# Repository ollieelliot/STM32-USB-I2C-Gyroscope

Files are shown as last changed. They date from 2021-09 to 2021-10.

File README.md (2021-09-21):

# STM32-USB-I2C-Gyroscope
Connecting an STM32F405RG microcontroller with a gyroscope through I2C as well as connecting USB B Micro, SWD and USART in order to learn more about circuit and PCB design.
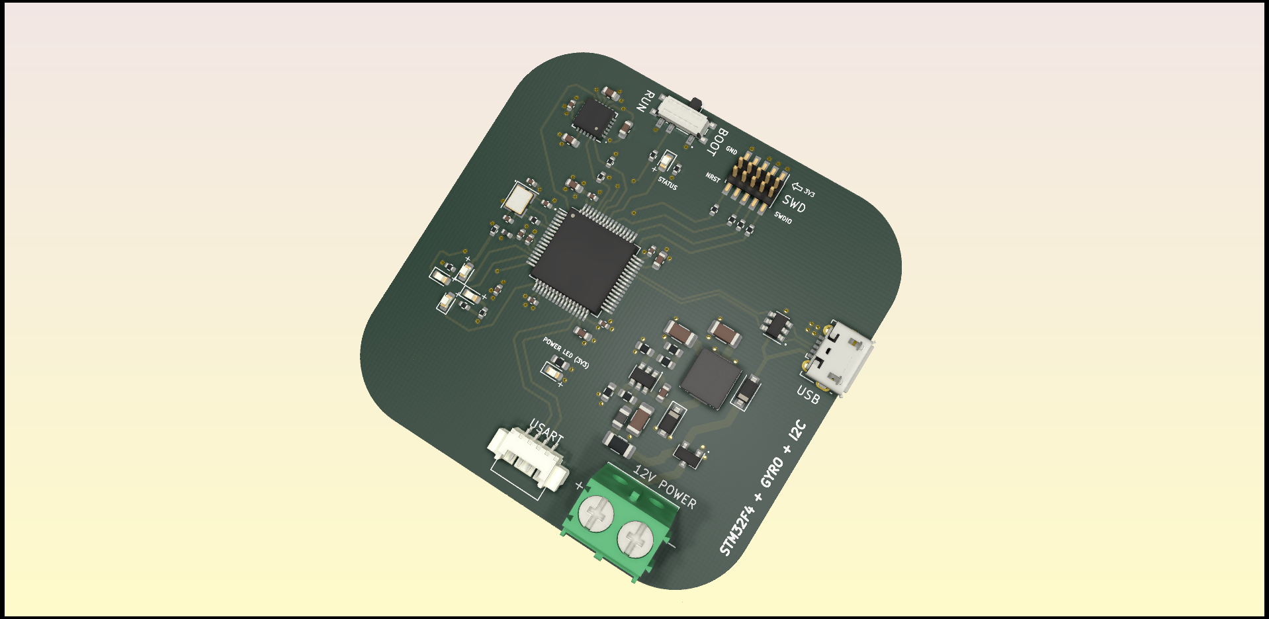
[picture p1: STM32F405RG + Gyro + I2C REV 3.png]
3D View


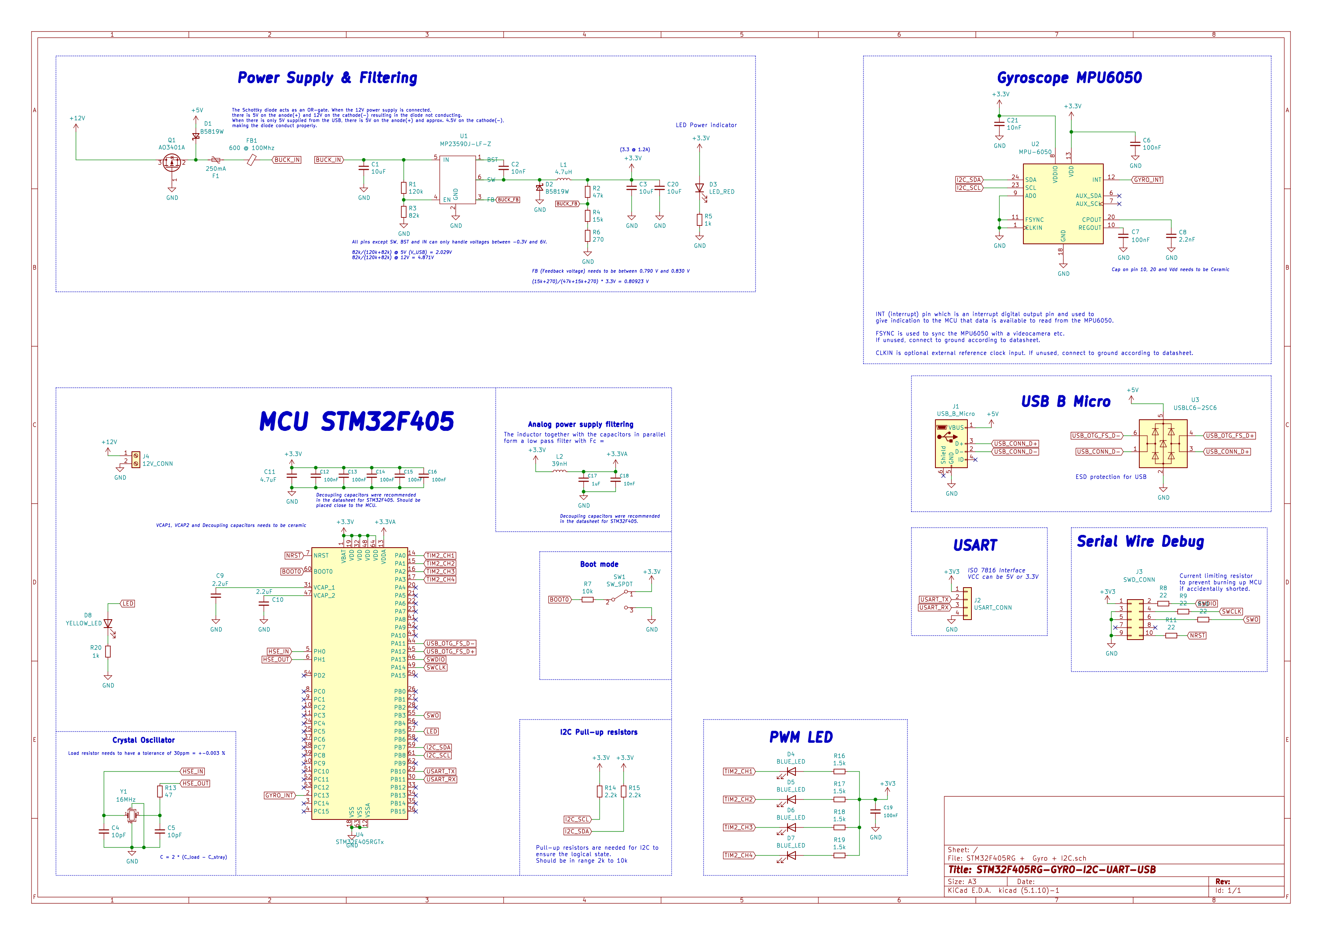
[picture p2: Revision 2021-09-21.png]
KiCad Schematic


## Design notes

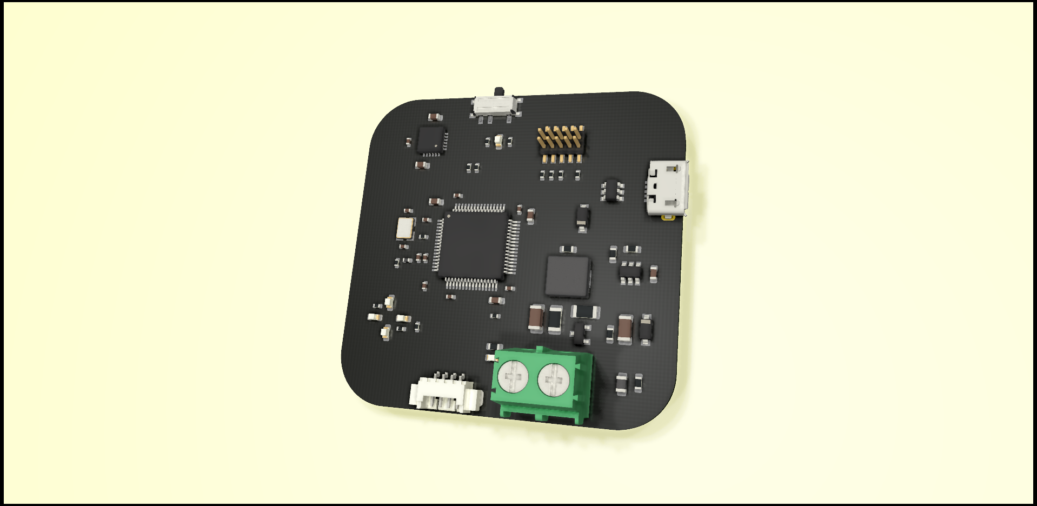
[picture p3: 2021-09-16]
STM32F405RG + Gyro + I2C.png

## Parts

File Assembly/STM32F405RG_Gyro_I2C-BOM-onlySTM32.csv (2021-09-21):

Comment | Designator | Footprint | LCSC
10uF | C1,C3,C20 | Capacitor_SMD:C_1206_3216Metric
4.7uF | C11 | Capacitor_SMD:C_0603_1608Metric
100nF | C6,C12,C13,C14,C15,C16,C19 | Capacitor_SMD:C_0402_1005Metric
1uF | C17 | Capacitor_SMD:C_0402_1005Metric
10nF | C18 | Capacitor_SMD:C_0402_1005Metric
10nF | C2,C21 | Capacitor_SMD:C_0603_1608Metric
10pF | C4,C5 | Capacitor_SMD:C_0402_1005Metric
100nF | C7 | Capacitor_SMD:C_0603_1608Metric
2.2nF | C8 | Capacitor_SMD:C_0603_1608Metric
2.2uF | C9,C10 | Capacitor_SMD:C_0603_1608Metric
B5819W | D1,D2 | Diode_SMD:D_SOD-123
LED_RED | D3 | LED_SMD:LED_0603_1608Metric
BLUE_LED | D4,D5,D6,D7 | LED_SMD:LED_0603_1608Metric
YELLOW_LED | D8 | LED_SMD:LED_0603_1608Metric
250mA | F1 | Fuse:Fuse_1206_3216Metric
600 @ 100Mhz | FB1 | Inductor_SMD:L_0805_2012Metric
USB_B_Micro | J1 | USB Footprint Library:USB_Micro-B_Molex-105017-0001
USART_CONN | J2 | Connector_Molex:Molex_PicoBlade_53048-0410_1x04_P1.25mm_Horizontal
SWD_CONN | J3 | Connector_PinHeader_1.27mm:PinHeader_2x05_P1.27mm_Vertical_SMD
12V_CONN | J4 | TerminalBlock_Phoenix:TerminalBlock_Phoenix_PT-1,5-2-5.0-H_1x02_P5.00mm_Horizontal
4.7uH | L1 | Inductor_SMD:L_Sunlord_MWSA0518_5.4x5.2mm | C408347
39nH | L2 | Inductor_SMD:L_0402_1005Metric
AO3401A | Q1 | Package_TO_SOT_SMD:SOT-23
120k | R1 | Resistor_SMD:R_0603_1608Metric
47 | R13 | Resistor_SMD:R_0402_1005Metric
2.2k | R14,R15 | Resistor_SMD:R_0402_1005Metric
1.5k | R16,R17,R18,R19 | Resistor_SMD:R_0402_1005Metric
47k | R2 | Resistor_SMD:R_0603_1608Metric
1k | R20 | Resistor_SMD:R_0402_1005Metric
82k | R3 | Resistor_SMD:R_0603_1608Metric
15k | R4 | Resistor_SMD:R_0603_1608Metric
1k | R5 | Resistor_SMD:R_0603_1608Metric
270 | R6 | Resistor_SMD:R_0603_1608Metric
10k | R7 | Resistor_SMD:R_0402_1005Metric
22 | R8,R9,R10,R11 | Resistor_SMD:R_0402_1005Metric
SW_SPDT | SW1 | Button_Switch_SMD:SW_SPDT_PCM12
MP2359DJ-LF-Z | U1 | Package_TO_SOT_SMD:SOT-23-6
MPU-6050 | U2 | Sensor_Motion:InvenSense_QFN-24_4x4mm_P0.5mm | C24112
USBLC6-2SC6 | U3 | Package_TO_SOT_SMD:SOT-23-6
STM32F405RGTx | U4 | Package_QFP:LQFP-64_10x10mm_P0.5mm | C15742
16MHz | Y1 | Crystal:Crystal_SMD_3225-4Pin_3.2x2.5mm

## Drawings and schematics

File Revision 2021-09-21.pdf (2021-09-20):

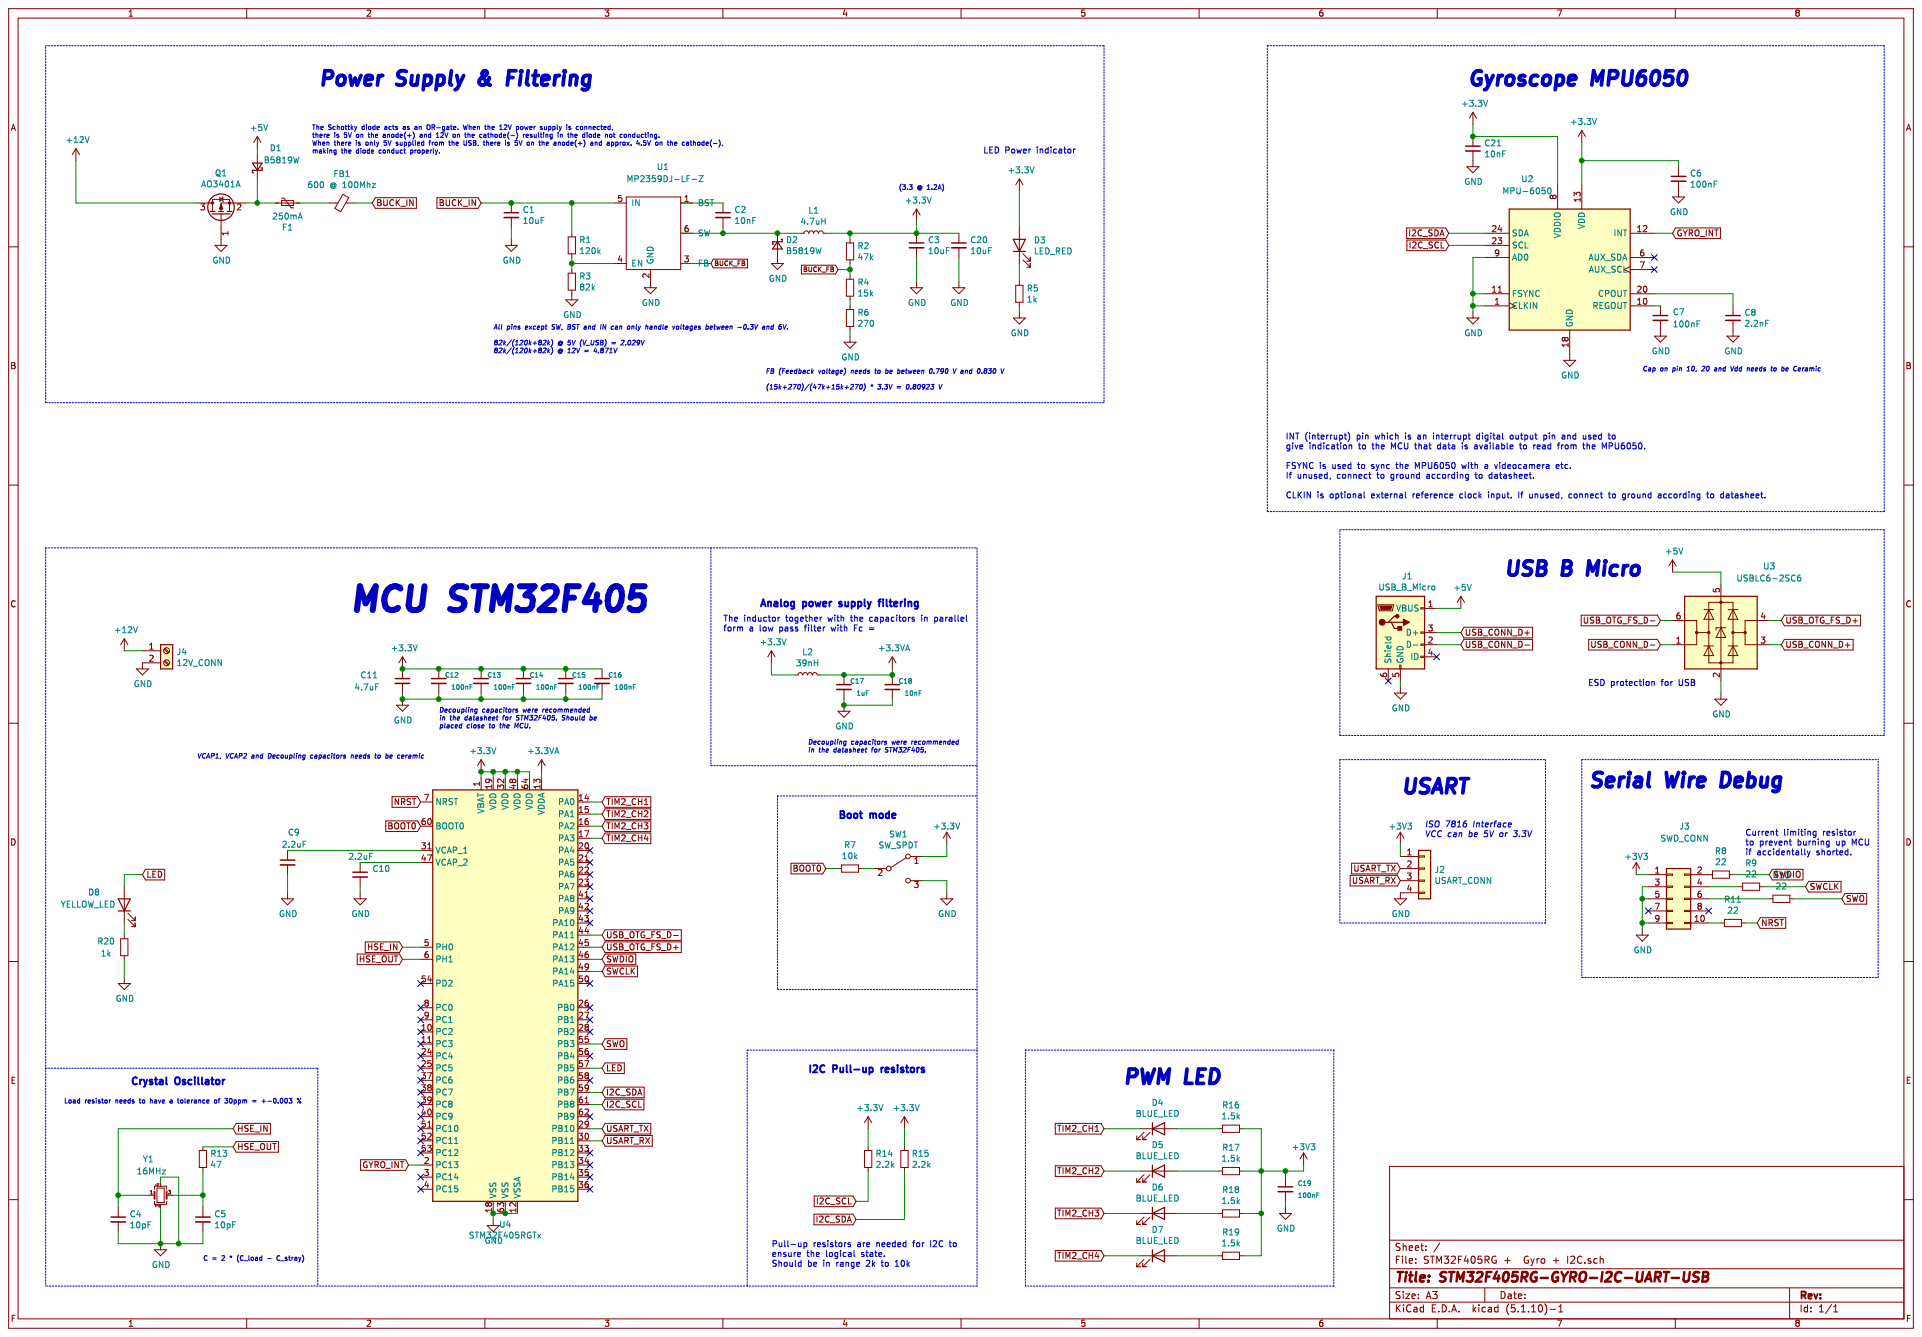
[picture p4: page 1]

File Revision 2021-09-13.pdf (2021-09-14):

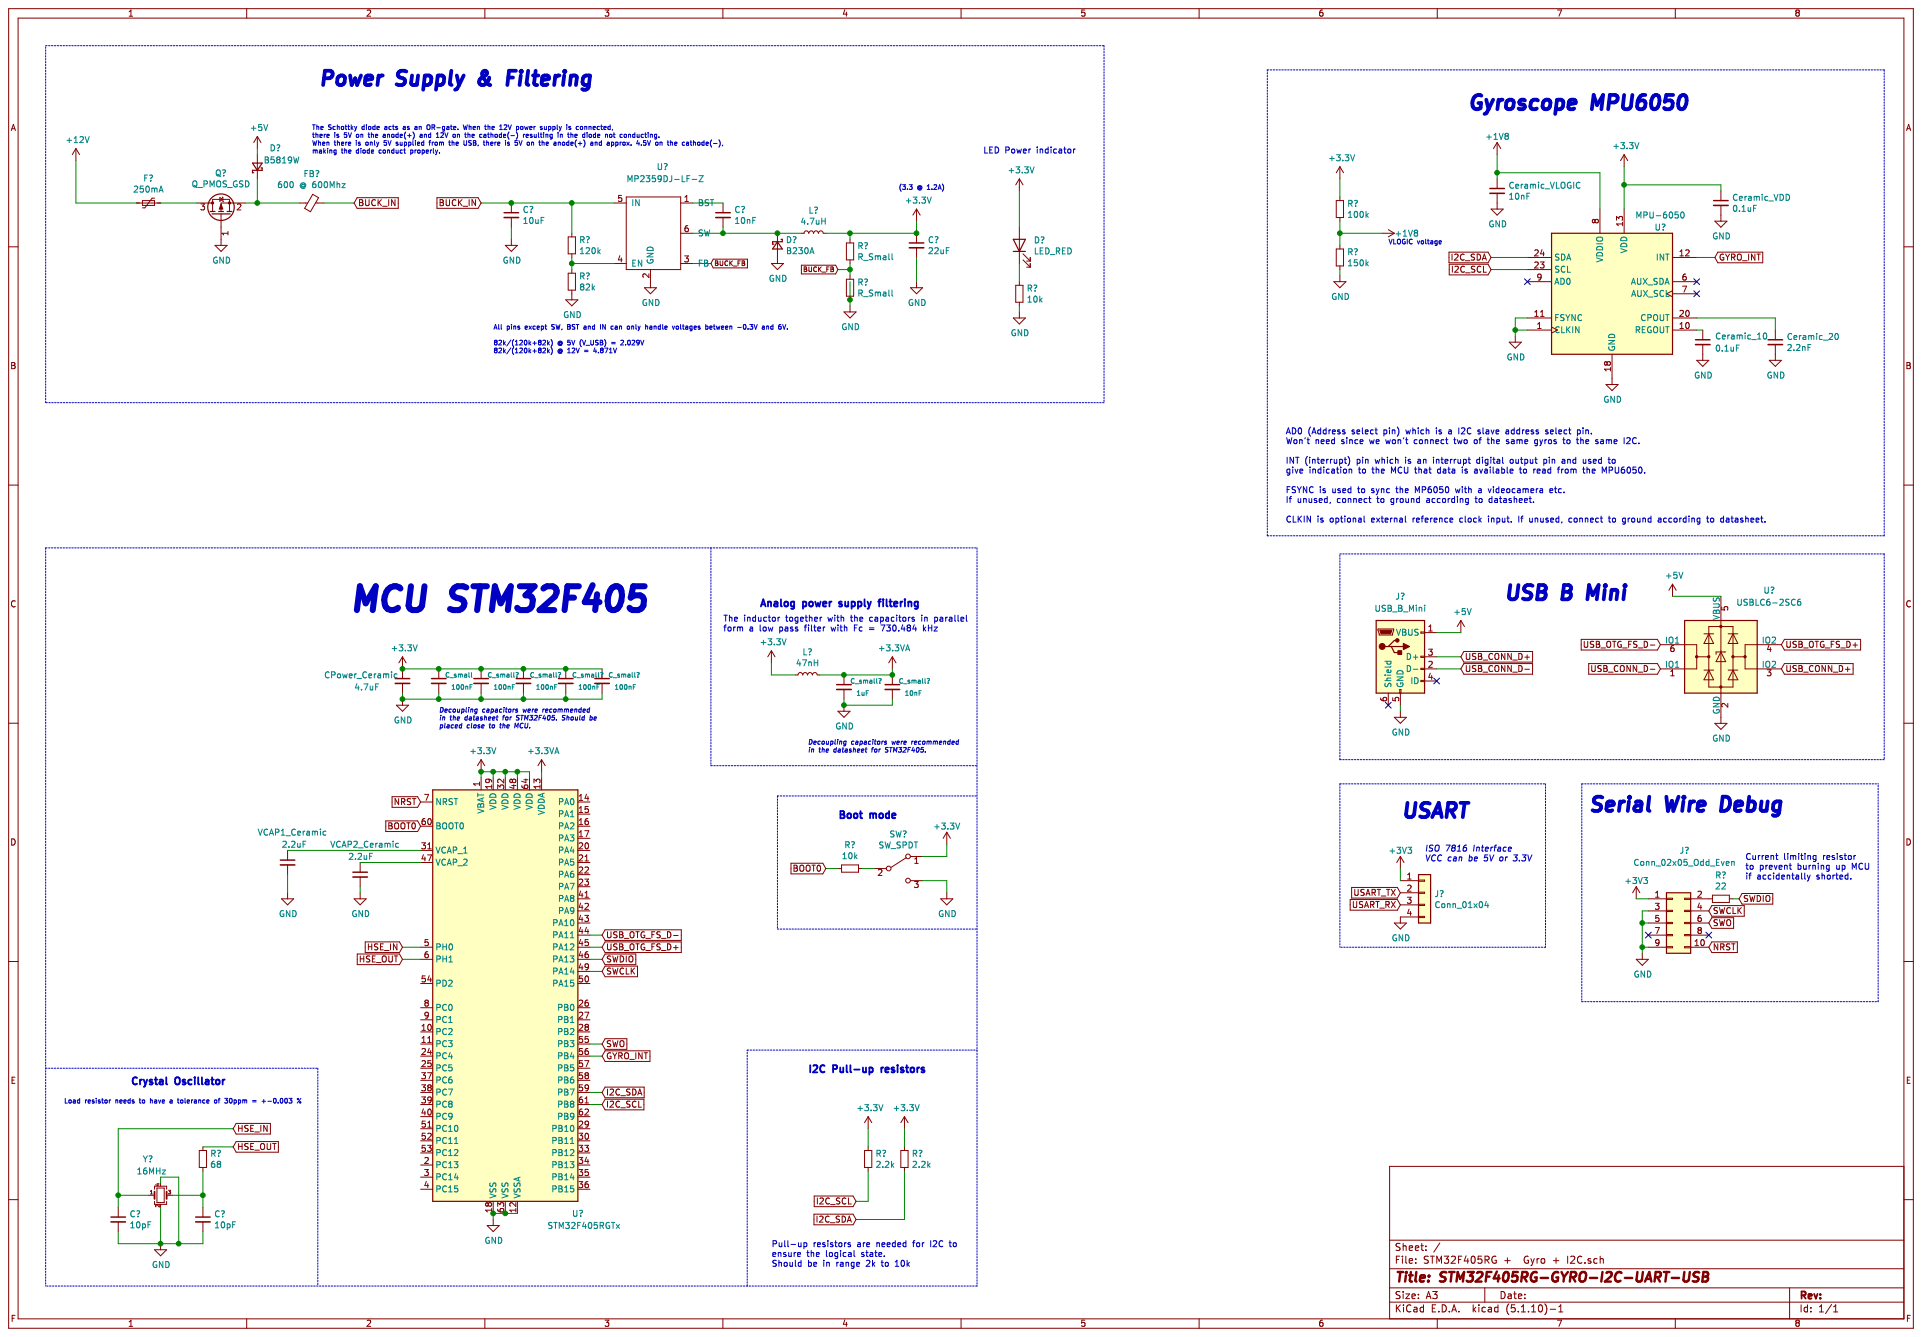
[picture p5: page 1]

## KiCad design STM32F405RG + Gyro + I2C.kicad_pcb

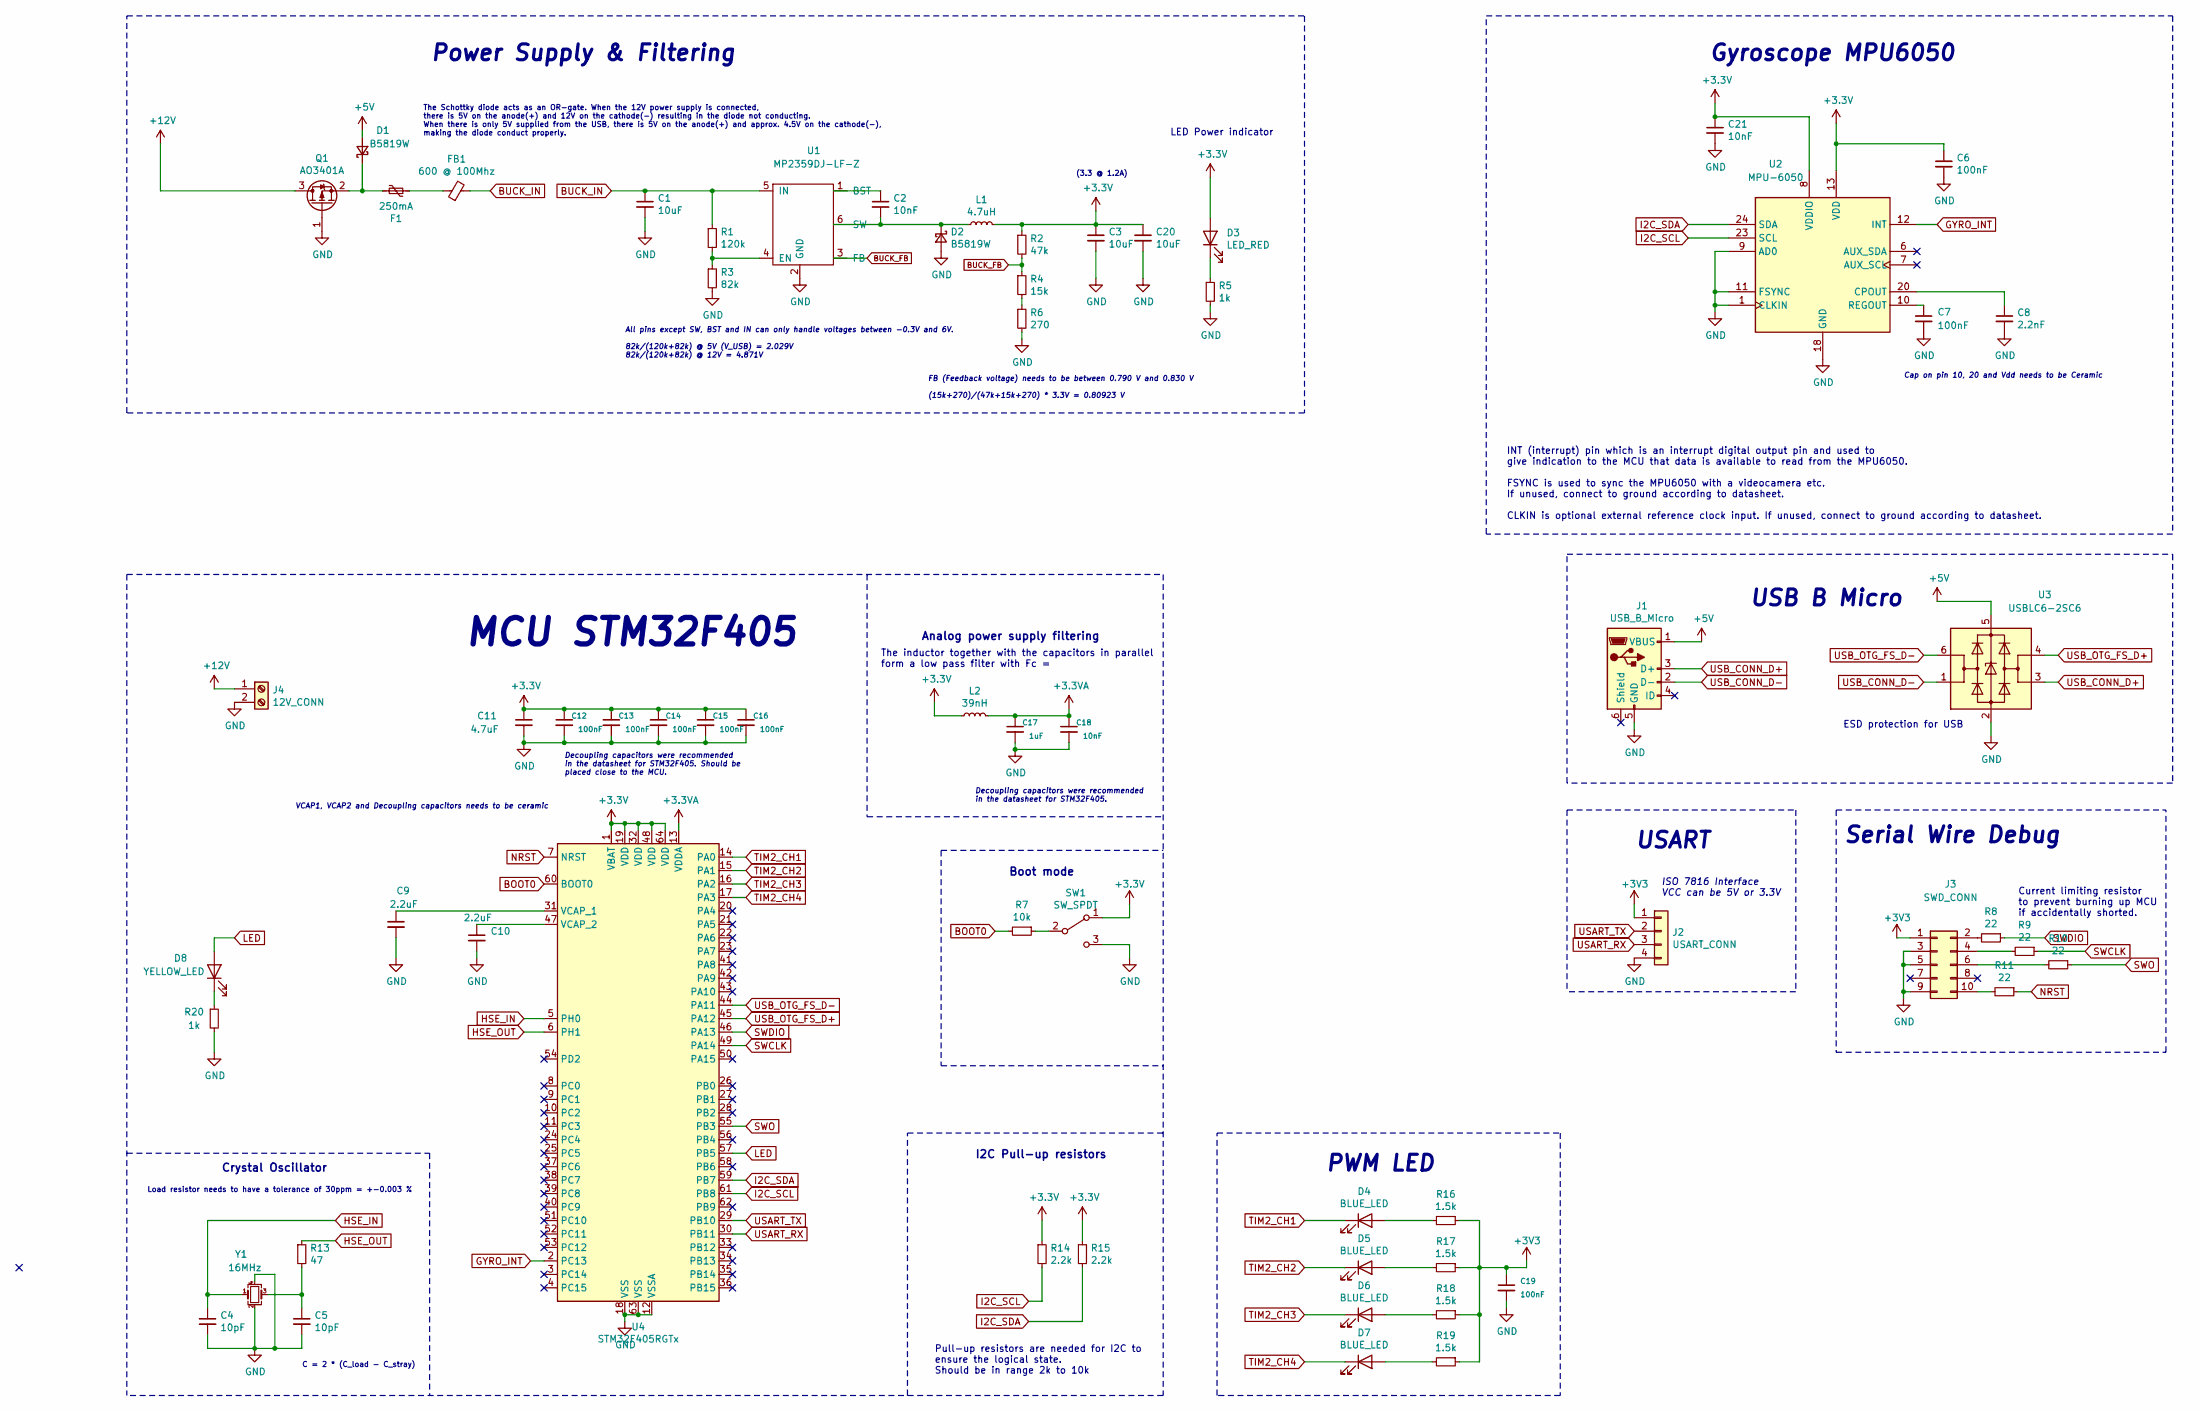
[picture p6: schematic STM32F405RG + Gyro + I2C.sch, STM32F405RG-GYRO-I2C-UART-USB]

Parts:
C1, C3, C20: 10uF; C_1206_3216Metric; LCSC C13585
C2, C21: 10nF; C_0603_1608Metric; LCSC C57112
C4, C5: 10pF; C_0402_1005Metric; LCSC C32949
C6, C12, C13, C14, C15, C16, C19: 100nF; C_0402_1005Metric; LCSC C1525
C7: 100nF; C_0603_1608Metric; LCSC C14663
C8: 2.2nF; C_0603_1608Metric; LCSC C1604
C9, C10: 2.2uF; C_0603_1608Metric; LCSC C23630
C11: 4.7uF; C_0603_1608Metric; LCSC C19666
C17: 1uF; C_0402_1005Metric; LCSC C52923
C18: 10nF; C_0402_1005Metric; LCSC C15195
D1, D2: B5819W; D_SOD-123; LCSC C8598
D3: LED_RED; LED_0603_1608Metric; LCSC C2286
D4, D5, D6, D7: BLUE_LED; LED_0603_1608Metric; LCSC C72041
D8: YELLOW_LED; LED_0603_1608Metric; LCSC C72038
F1: 250mA; Fuse_1206_3216Metric; LCSC C369159
FB1: 600 @ 100Mhz; L_0805_2012Metric; LCSC C1017
J1: USB_B_Micro; USB_Micro-B_Molex-105017-0001
J2: USART_CONN; Molex_PicoBlade_53048-0410_1x04_P1.25mm_Horizontal
J3: SWD_CONN; PinHeader_2x05_P1.27mm_Vertical_SMD
J4: 12V_CONN; TerminalBlock_Phoenix_PT-1,5-2-5.0-H_1x02_P5.00mm_Horizontal
L1: 4.7uH; L_Sunlord_MWSA0518_5.4x5.2mm; LCSC C408347
L2: 39nH; L_0402_1005Metric; LCSC C26443
Q1: AO3401A; SOT-23; LCSC C15127
R1: 120k; R_0603_1608Metric; LCSC C25808
R2: 47k; R_0603_1608Metric; LCSC C25819
R3: 82k; R_0603_1608Metric; LCSC C23254
R4: 15k; R_0603_1608Metric; LCSC C22809
R5: 1k; R_0603_1608Metric; LCSC C369159
R6: 270; R_0603_1608Metric; LCSC C22966
R7: 10k; R_0402_1005Metric; LCSC C25744
R8, R9, R10, R11: 22; R_0402_1005Metric; LCSC C25092
R13: 47; R_0402_1005Metric; LCSC C25118
R14, R15: 2.2k; R_0402_1005Metric; LCSC C25879
R16, R17, R18, R19: 1.5k; R_0402_1005Metric; LCSC C25867
R20: 1k; R_0402_1005Metric; LCSC C21190
SW1: SW_SPDT; SW_SPDT_PCM12
U1: MP2359DJ-LF-Z; SOT-23-6; LCSC C14259
U2: MPU-6050; InvenSense_QFN-24_4x4mm_P0.5mm; LCSC C24112
U3: USBLC6-2SC6; SOT-23-6; LCSC C7519
U4: STM32F405RGTx; LQFP-64_10x10mm_P0.5mm; LCSC C15742
Y1: 16MHz; Crystal_SMD_3225-4Pin_3.2x2.5mm; LCSC C13738

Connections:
+3.3VA: C17.1, C18.1, L2.2, U4.13 (VDDA)
+5V: D1.2 (A), J1.1 (VBUS), U3.5 (VBUS)
+12V: J4.1, Q1.3 (D)
BOOT0: R7.2, U4.60 (BOOT0)
BUCK_FB: R2.2, R4.1, U1.3 (FB)
BUCK_IN: C1.1, FB1.2, R1.1, U1.5 (IN)
GND: C1.2, C3.2, C4.2, C5.2, C6.2, C7.2, C8.2, C9.2, C10.2, C11.2, C12.2, C13.2, C14.2, C15.2, C16.2, C17.2, C18.2, C19.2, C20.2, C21.2, D2.2 (A), J1.5 (GND), J2.4, J3.3, J3.5, J3.9, J4.2, Q1.1 (G), R3.2, R5.2, R6.2, R20.2, SW1.3 (C), U1.2 (GND), U2.1 (CLKIN), U2.9 (AD0), U2.11 (FSYNC), U2.18 (GND), U3.2 (GND), U4.12 (VSSA), U4.18 (VSS), U4.63 (VSS), Y1.2, Y1.4
GYRO_INT: U2.12 (INT), U4.2 (PC13)
HSE_IN: C4.1, U4.5 (PH0), Y1.1
HSE_OUT: R13.1, U4.6 (PH1)
I2C_SCL: R14.2, U2.23 (SCL), U4.61 (PB8)
I2C_SDA: R15.2, U2.24 (SDA), U4.59 (PB7)
LED: D8.2 (A), U4.57 (PB5)
NRST: R11.1, U4.7 (NRST)
unnamed: C2.1, U1.1 (BST)
unnamed: C2.2, D2.1 (K), L1.1, U1.6 (SW)
unnamed: C5.1, R13.2, Y1.3
unnamed: C7.1, U2.10 (REGOUT)
unnamed: C8.1, U2.20 (CPOUT)
unnamed: C9.1, U4.31 (VCAP_1)
unnamed: C10.1, U4.47 (VCAP_2)
unnamed: D1.1 (K), F1.2, Q1.2 (S)
unnamed: D3.1 (K), R5.1
unnamed: D4.2 (A), R16.2
unnamed: D5.2 (A), R17.2
unnamed: D6.2 (A), R18.2
unnamed: D7.2 (A), R19.2
unnamed: D8.1 (K), R20.1
unnamed: F1.1, FB1.1
unnamed: J3.2, R8.2
unnamed: J3.4, R9.2
unnamed: J3.6, R10.2
unnamed: J3.10, R11.2
unnamed: R1.2, R3.1, U1.4 (EN)
unnamed: R4.2, R6.1
unnamed: R7.1, SW1.2 (B)
SWCLK: R9.1, U4.49 (PA14)
SWDIO: R8.1, U4.46 (PA13)
SWO: R10.1, U4.55 (PB3)
TIM2_CH1: D4.1 (K), U4.14 (PA0)
TIM2_CH2: D5.1 (K), U4.15 (PA1)
TIM2_CH3: D6.1 (K), U4.16 (PA2)
TIM2_CH4: D7.1 (K), U4.17 (PA3)
USART_RX: J2.3, U4.30 (PB11)
USART_TX: J2.2, U4.29 (PB10)
USB_CONN_D+: J1.3 (D+), U3.3 (I/O2)
USB_CONN_D-: J1.2 (D-), U3.1 (I/O1)
USB_OTG_FS_D+: U3.4 (I/O2), U4.45 (PA12)
USB_OTG_FS_D-: U3.6 (I/O1), U4.44 (PA11)

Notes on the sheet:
Pull-up resistors are needed for I2C to ensure the logical state. Should be in range 2k to 10k
INT (interrupt) pin which is an interrupt digital output pin and used to give indication to the MCU that data is available to read from the MPU6050. FSYNC is used to sync the MPU6050 with a videocamera etc. If unused, connect to ground according to datasheet. CLKIN is optional external reference cl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
LED Power indicator
Load resistor needs to have a tolerance of 30ppm = +-0.003 %
(3.3 @ 1.2A)
All pins except SW, BST and IN can only handle voltages between -0.3V and 6V. 82k/(120k+82k) @ 5V (V_USB) = 2.029V 82k/(120k+82k) @ 12V = 4.871V
The Schottky diode acts as an OR-gate. When the 12V power supply is connected, there is 5V on the anode(+) and 12V on the cathode(-) resulting in the diode not conducting. When there is only 5V supplied from the USB, there is 5V on the anode(+) and approx. 4.5V on the cathode(-), making the diode c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
Serial Wire Debug
Power Supply & Filtering
USB B Micro
MCU STM32F405
Current limiting resistor to prevent burning up MCU if accidentally shorted.
The inductor together with the capacitors in parallel form a low pass filter with Fc =
Analog power supply filtering
Decoupling capacitors were recommended in the datasheet for STM32F405.
Crystal Oscillator
I2C Pull-up resistors
Boot mode
Decoupling capacitors were recommended in the datasheet for STM32F405. Should be placed close to the MCU.
ISO 7816 Interface VCC can be 5V or 3.3V
USART
ESD protection for USB
C = 2 * (C_load - C_stray)
FB (Feedback voltage) needs to be between 0.790 V and 0.830 V (15k+270)/(47k+15k+270) * 3.3V = 0.80923 V
Cap on pin 10, 20 and Vdd needs to be Ceramic
VCAP1, VCAP2 and Decoupling capacitors needs to be ceramic
PWM LED
Gyroscope MPU6050

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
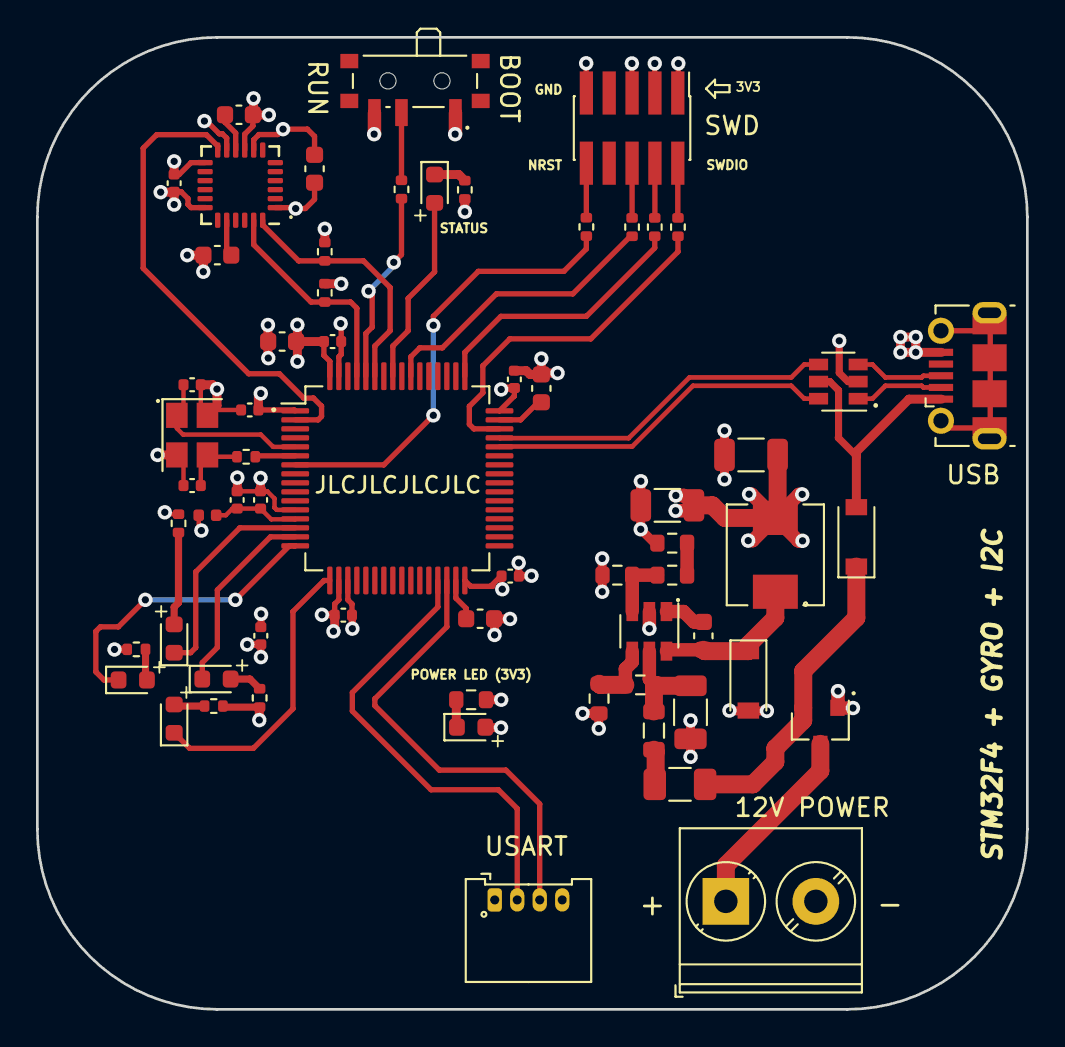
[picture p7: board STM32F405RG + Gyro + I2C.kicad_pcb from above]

Board: 4 copper layers, 55.0 x 54.0 mm, 63 parts (0 on the bottom side), 50 nets.

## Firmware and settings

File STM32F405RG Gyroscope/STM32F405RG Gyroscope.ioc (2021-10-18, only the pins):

Mcu.UserName=STM32F405RGTx
PA0-WKUP.Signal=S_TIM2_CH1_ETR
PA1.Signal=S_TIM2_CH2
PA11.Signal=USB_OTG_FS_DM
PA12.Signal=USB_OTG_FS_DP
PA13.Signal=SYS_JTMS-SWDIO
PA14.Signal=SYS_JTCK-SWCLK
PA2.Signal=S_TIM2_CH3
PA3.Signal=S_TIM2_CH4
PA4.GPIO_Label=GYRO_CS
PA4.Signal=GPIO_Output
PB10.Signal=USART3_TX
PB11.Signal=USART3_RX
PB3.Signal=SYS_JTDO-SWO
PB5.GPIO_Label=LED
PB5.Signal=GPIO_Output
PB6.Signal=I2C1_SCL
PB7.Signal=I2C1_SDA
PC4.GPIO_Label=MPU6050_INT
PC4.Signal=GPIO_Input
PH0-OSC_IN.Signal=RCC_OSC_IN
PH1-OSC_OUT.Signal=RCC_OSC_OUT

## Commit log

2021-09-12 Added more things to the circuit
2021-09-12 Added more things to circuit
    [STM32F405RG + Gyro + I2C.sch]
2021-09-14 Added annotations
    [STM32F405RG + Gyro + I2C.sch]
2021-09-15 Started PCB layout
    [STM32F405RG + Gyro + I2C.sch]
2021-09-16 Minor changes
    [STM32F405RG + Gyro + I2C.sch]
2021-09-16 Changed power supply layout
    [STM32F405RG + Gyro + I2C.kicad_pcb, STM32F405RG + Gyro + I2C.sch]
2021-09-17 Uploaded new PDF of the the latest schematic
2021-09-18 Changes & PCB routing
    Changed pin on LED, started routing signals and differential pairs
    [STM32F405RG + Gyro + I2C.kicad_pcb, STM32F405RG + Gyro + I2C.sch]
2021-09-18 Revert "Changes & PCB routing"
    This reverts commit bada82a912c55c4199179019eb8492b380a79c23, reversing
    changes made to f585d00e69f4fe89e0924f05bd4fcbc467184eeb.
2021-09-19 Fixed layout and added text to silkscreen
    [STM32F405RG + Gyro + I2C.kicad_pcb, STM32F405RG + Gyro + I2C.sch]
2021-09-19 Changes
    FIX: Changed SWD connector from socket to header
    [STM32F405RG + Gyro + I2C.kicad_pcb, STM32F405RG + Gyro + I2C.sch]
2021-09-20 Added BOM file
    [STM32F405RG + Gyro + I2C.csv, STM32F405RG + Gyro + I2C.kicad_pcb, STM32F405RG + Gyro + I2C.sch]
2021-09-20 Changed gyroscope, added gerber and assembly files
    -Changed Gyroscope from MPU-6000 to MPU-6050
    -Added Gerber and Assembly files
    [STM32F405RG + Gyro + I2C-B_Cu.gbr, STM32F405RG + Gyro + I2C-B_Mask.gbr, STM32F405RG + Gyro + I2C-B_Paste.gbr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]
